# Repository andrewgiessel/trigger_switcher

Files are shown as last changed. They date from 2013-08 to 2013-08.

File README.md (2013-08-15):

trigger_switcher
================

Arduino Code to multiplex a single trigger through a series of digital lines.

`blink_switch` and `led_and_serial` are early drafts of getting the logic working.  `passthru` is the final code we'll be using.

We're using a teensy 2.0++ board, and the PCB files are for Eagle.

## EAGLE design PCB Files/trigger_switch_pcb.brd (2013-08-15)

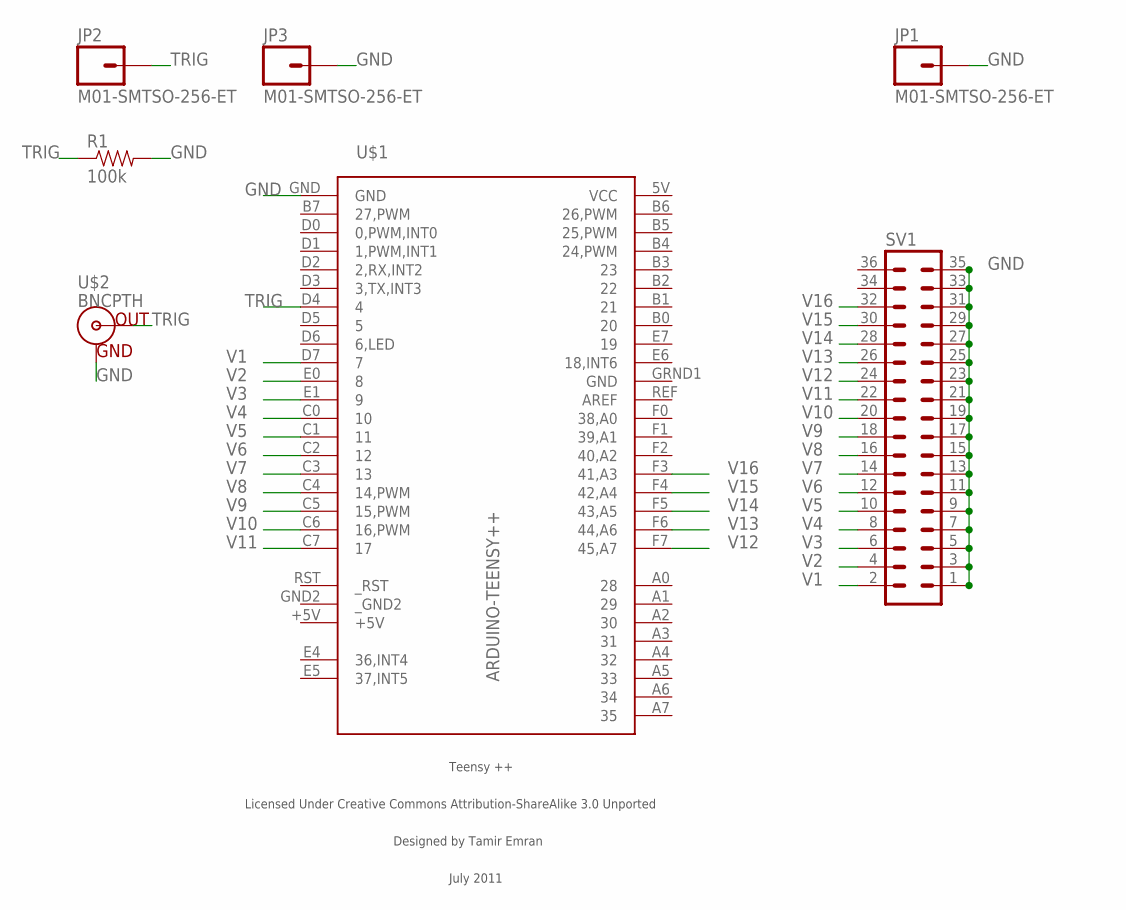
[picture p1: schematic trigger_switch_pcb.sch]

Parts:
JP1, JP2, JP3: M01-SMTSO-256-ET; SMTSO-256-ET
R1: 100k; AXIAL-0.5
SV1: MA18-2
U$1: ARDUINO-TEENSY++; TEENSY++
U$2: BNCPTH; BNC

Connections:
+5V: U$1.+5V
GND: JP1.P$1, JP3.P$1, R1.P$2 (2), SV1.1, SV1.3, SV1.5, SV1.7, SV1.9, SV1.11, SV1.13, SV1.15, SV1.17, SV1.19, SV1.21, SV1.23, SV1.25, SV1.27, SV1.29, SV1.31, SV1.33, SV1.35, U$1.GND, U$1.GRND1 (GND), U$2.GND
TRIG: JP2.P$1, R1.P$1 (1), U$1.D4 (4), U$2.S (OUT)
V1: SV1.2, U$1.D7 (7)
V2: SV1.4, U$1.E0 (8)
V3: SV1.6, U$1.E1 (9)
V4: SV1.8, U$1.C0 (10)
V5: SV1.10, U$1.C1 (11)
V6: SV1.12, U$1.C2 (12)
V7: SV1.14, U$1.C3 (13)
V8: SV1.16, U$1.C4 (14,PWM)
V9: SV1.18, U$1.C5 (15,PWM)
V10: SV1.20, U$1.C6 (16,PWM)
V11: SV1.22, U$1.C7 (17)
V12: SV1.24, U$1.F7 (45,A7)
V13: SV1.26, U$1.F6 (44,A6)
V14: SV1.28, U$1.F5 (43,A5)
V15: SV1.30, U$1.F4 (42,A4)
V16: SV1.32, U$1.F3 (41,A3)
VCC: U$1.5V (VCC)
_GND2: U$1.GND2 (_GND2)

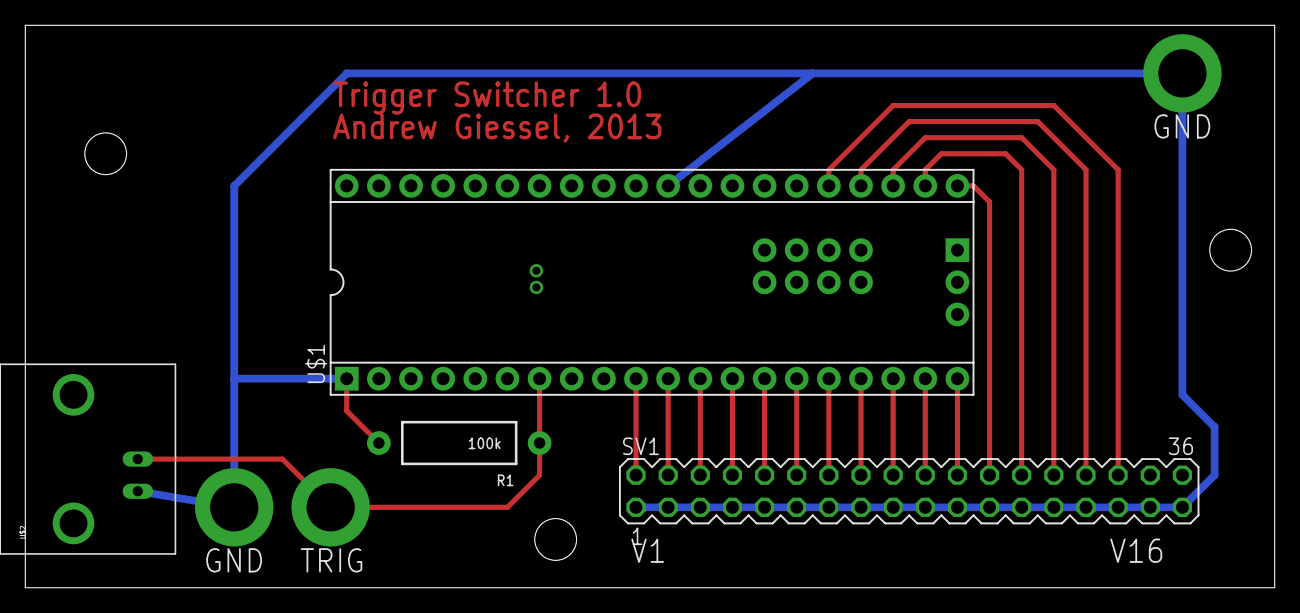
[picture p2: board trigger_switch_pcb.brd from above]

Board: 2 copper layers, 98.7 x 44.4 mm, 10 parts (0 on the bottom side), 18 nets.

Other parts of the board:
U$3, U$4, U$6: STAND-OFF

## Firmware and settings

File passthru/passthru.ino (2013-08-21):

/*

*/


const int triggerPin = 4;

int outPin = 7;
int triggerVal = 0;
char inputVal = '0';
int defaultPin = 7;

boolean wasTriggered = 0;

char triggerSequence[2048];
int triggerPosition = 0;

void setup() {
   pinMode(triggerPin, INPUT);

   // set pins as out
   pinMode(7, OUTPUT); // valve 0
   pinMode(8, OUTPUT);
   pinMode(9, OUTPUT);
   pinMode(10, OUTPUT);
   pinMode(11, OUTPUT);
   pinMode(12, OUTPUT);
   pinMode(13, OUTPUT);
   pinMode(14, OUTPUT);
   pinMode(15, OUTPUT);
   pinMode(16, OUTPUT);
   pinMode(17, OUTPUT);
   pinMode(45, OUTPUT);
   pinMode(44, OUTPUT);
   pinMode(43, OUTPUT);
   pinMode(42, OUTPUT);
   pinMode(41, OUTPUT); // valve 15
   
   // set valve 0 to on by default
   digitalWrite(defaultPin, HIGH);
   
   // clear all values in the trigger sequence - default pin is 0 to start
   memset(triggerSequence, '0', sizeof(triggerSequence));

   Serial.begin(9600);
 }

/* 
loop has two stages

1)  check for new serial input that indicates a series of states.
    This will be a string of hexidecimal characters, 0-9 or a-f
    These will be mapped to valve positions, 0-15.  Saved as a 
    character array in 'triggerSequence'.  Current valve is saved
    as an index called 'triggerPosition'
    
    Alternatively, you can send a two character sequence 'X-' where the -
    is the new default valve (same convention as the sequence values).  
    This can be used to manually switch the valves. 
    
2)  Check the state of the triggerPin and pass thru it's state to
    the correct pin, and turn off valve 0.  This will continually 
    be set through each time in the loop, which is wasteful but no 
    big deal and makes signal generation easy.  Once high, mark 
    'wasTriggered' as true.
    
    If the pin is low, and wasTriggered is true, then we've transitioned
    out.  Turn on valve 0, turn off the current valve, and increment
    the triggerPosition.  
*/      
void loop(){
  // serial
  if (Serial.available()>0) {
    memset(triggerSequence, pin2char(defaultPin), sizeof(triggerSequence));
    triggerPosition = 0;

    Serial.readBytesUntil('\n', triggerSequence, 2048);
    
    if (triggerSequence[0] == 'X') { // need to set the default pin to something else
      int newDefaultPin = char2pin(triggerSequence[1]);
      if (newDefaultPin != defaultPin) {
        digitalWrite(defaultPin, LOW);
        defaultPin = newDefaultPin;
        memset(triggerSequence, pin2char(defaultPin), sizeof(triggerSequence));
      }  
    } else {
      outPin = char2pin(triggerSequence[triggerPosition]);  
    }

    digitalWrite(defaultPin, HIGH); // reset so valve 0 is on
    
  }  
  // pin logic
  triggerVal = digitalRead(triggerPin);
  if (triggerVal == HIGH) {
    // set default pin off and out pin on
    if (outPin != defaultPin) {
      digitalWrite(outPin, HIGH);
      digitalWrite(defaultPin, LOW);
    }
    //delay(10);
    wasTriggered = 1;
  } else {
    // set outpin off and default pin on
     if (outPin != defaultPin) {
       digitalWrite(outPin, LOW);
       digitalWrite(defaultPin, HIGH);
     }
    //delay(10);
    if (wasTriggered) {
      triggerPosition += 1;
      outPin = char2pin(triggerSequence[triggerPosition]);  
      wasTriggered = 0;
    }
  }
}

// this code is to map serial character to the right pin for each valve
int char2pin(char inputVal) {
     int out;
    
    switch (inputVal) {
      case '0':
        out = 7;
        break;
      case '1':
        out = 8;
        break;
      case '2':
        out = 9;
        break;
      case '3':
        out = 10;
        break;
      case '4':
        out = 11;
        break;
      case '5':
        out = 12;
        break;
      case '6':
        out = 13;
        break;
      case '7':
        out = 14;
        break;
      case '8':
        out = 15;
        break;
      case '9':
        out = 16;
        break;
      case 'a':
        out = 17;
        break;
      case 'b':
        out = 45;
        break;
      case 'c':
        out = 44;
        break;
      case 'd':
        out = 43;
        break;
      case 'e':
        out = 42;
        break;
      case 'f':
        out = 41;
        break;
      case '\0':  // string termination: valve 0
        out = defaultPin;
        break;
      default: // anything weird:  valve 0
        out = defaultPin;
        break;
    }
    Serial.print("Next pin: ");
    Serial.println(out);
    
    Serial.flush();
    return out;
}

// this code does the reverse, it returns a valid serial character for a given pin number
char pin2char(int pinNumber) {
     char out;
    
    switch (pinNumber) {
      case 7:
        out = '0';
        break;
      case 8:
        out = '1';
        break;
      case 9:
        out = '2';
        break;
      case 10:
        out = '3';
        break;
      case 11:
        out = '4';
        break;
      case 12:
        out = '5';
        break;
      case 13:
        out = '6';
        break;
      case 14:
        out = '7';
        break;
      case 15:
        out = '8';
        break;
      case 16:
        out = '9';
        break;
      case 17:
        out = 'a';
        break;
      case 45:
        out = 'b';
        break;
      case 44:
        out = 'c';
        break;
      case 43:
        out = 'd';
        break;
      case 42:
        out = 'e';
        break;
      case 41:
        out = 'f';
        break;
      default: // anything weird:  valve 0
        out = '\0';
        break;
    }
    return out;
}

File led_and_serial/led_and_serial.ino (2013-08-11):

int ledPin = 6;
int delayAmount = 1000;

void setup(){
// Do stuff once
  pinMode(ledPin, OUTPUT);
  Serial.begin(9600); // USB is always 12 Mbit/sec

}

void loop(){
// Do stuff repeatedly
   if(Serial.available()>0) // if there is data to read
   {
    delayAmount = Serial.parseInt(); // read data
    Serial.flush();
   }
   digitalWrite(ledPin, HIGH);
   Serial.println("high");
   delay(delayAmount);
   digitalWrite(ledPin, LOW);
   Serial.println("low");
   delay(delayAmount);
}

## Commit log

2013-08-11 initial commit
    simple example with an LED
    the particular pin depends on the device. working with a teensy2.0++
    and a duemilanove
2013-08-11 blink_val update
    getting weird bugs where it just keeps flashing, instead of only
    flashing when triggered from +5V… bad hardware? bad breadboard?
    trying to switch on single chars --- so have to have the case statement
    [blink_switch.ino]
2013-08-12 Update blink_switch.ino
    fixed switch statement (needed break; after every case!)
    also, made inputVal a <char> for the switch
    [blink_switch.ino]
2013-08-12 Update passthru.ino
    broke out update thru pin to seperate function
    added 10 ms delay to deal with switch bounce, remove later
    note that strings terminate with \0 - had to add a case statement to treat it as a '0'
    added code to swap pins (valve 0 on/off at the same time as other valve off/on)
    used memset to set all the memory in the the triggerSequence buffer to '0'
    [passthru.ino]
2013-08-15 initial commit of PCB eagle files
    One for the schematic, one for the board
    [trigger_switch_pcb.brd, trigger_switch_pcb.sch]
2013-08-15 update to wiring diagram
    i think i have the board schematic done! All grounds on the bottom,
    all signals on the top
    [trigger_switch_pcb.brd, trigger_switch_pcb.sch]
2013-08-15 Final? Changes to board
    added standoffs, resized board
    [trigger_switch_pcb.brd]
2013-08-15 fixed text typos
    [trigger_switch_pcb.brd]
2013-08-15 final changes to .brd
    [trigger_switch_pcb.brd]
2013-08-21 adding manual switch via serial
    Lots of changes here to make the default valve (generally '0') to be
    whatever you want.
    * renamed 'updateThruPin() to char2pin(), and it returns a value rather
    than change the global variables.
    * added pin2char() to do the reverse, which is used for setting the
    default values in the state sequence.
    * changed the trigger section to check if the 'outPin' (which is in
    triggerSequence[]) is the same as the default pin. This happens when
    you initialize the array, or if you run off the end of the sequence.
    was setting the pin high and then low very quickly. Still increments,
    it just doesn't change the pin states.
    [passthru.ino]

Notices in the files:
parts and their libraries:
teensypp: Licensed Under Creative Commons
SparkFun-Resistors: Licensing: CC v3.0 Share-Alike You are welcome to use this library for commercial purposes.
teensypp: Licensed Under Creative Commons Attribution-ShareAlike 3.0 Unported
